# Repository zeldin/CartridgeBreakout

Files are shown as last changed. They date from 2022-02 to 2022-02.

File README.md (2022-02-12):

Cartridge Breakout
==================

This is a PCB to break out the signals of a 44-contact 2.54 mm card edge
connector, as used in cartridges for the C64, to pin headers.  It was
designed for use with the Orange Cartridge, but can be used with any C64
cartridge, or even other compatible card edge devices.

The board can be used for testing, debugging and prototyping cartridges
and FPGA cartridge gateware and software.

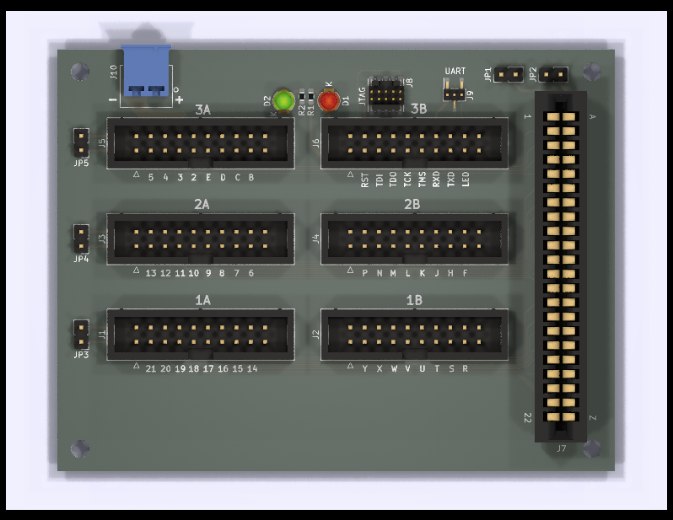
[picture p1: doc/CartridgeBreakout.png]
Render of the board


Features
--------

- 40 of the 44 contacts are routed to individual pins compatible
  with IDC or Dupont wiring.

- The 4 corner contacts are instead connected to a ground plane
  which is available on 40 pins, one for each signal pin.

- There is a 5V power plane which can be used to inject power into
  contacts 2 and 3, or just one of them if so desired.

- There is a 5-signal JTAG/SWD breakout from a 2x5 1.27 mm pin header,
  as a wired side channel to the cartridge.

- There is also a 2-signal UART breakout from a 1x3 1.27 mm pin header,
  likewise a wired side channel.

- There are two LEDs which can be controlled with a single pin, to support
  semi-automated testing setups.

Documentation
-------------

**[Building instructions](doc/Building.md)**  
**[User manual](doc/UserManual.md)**

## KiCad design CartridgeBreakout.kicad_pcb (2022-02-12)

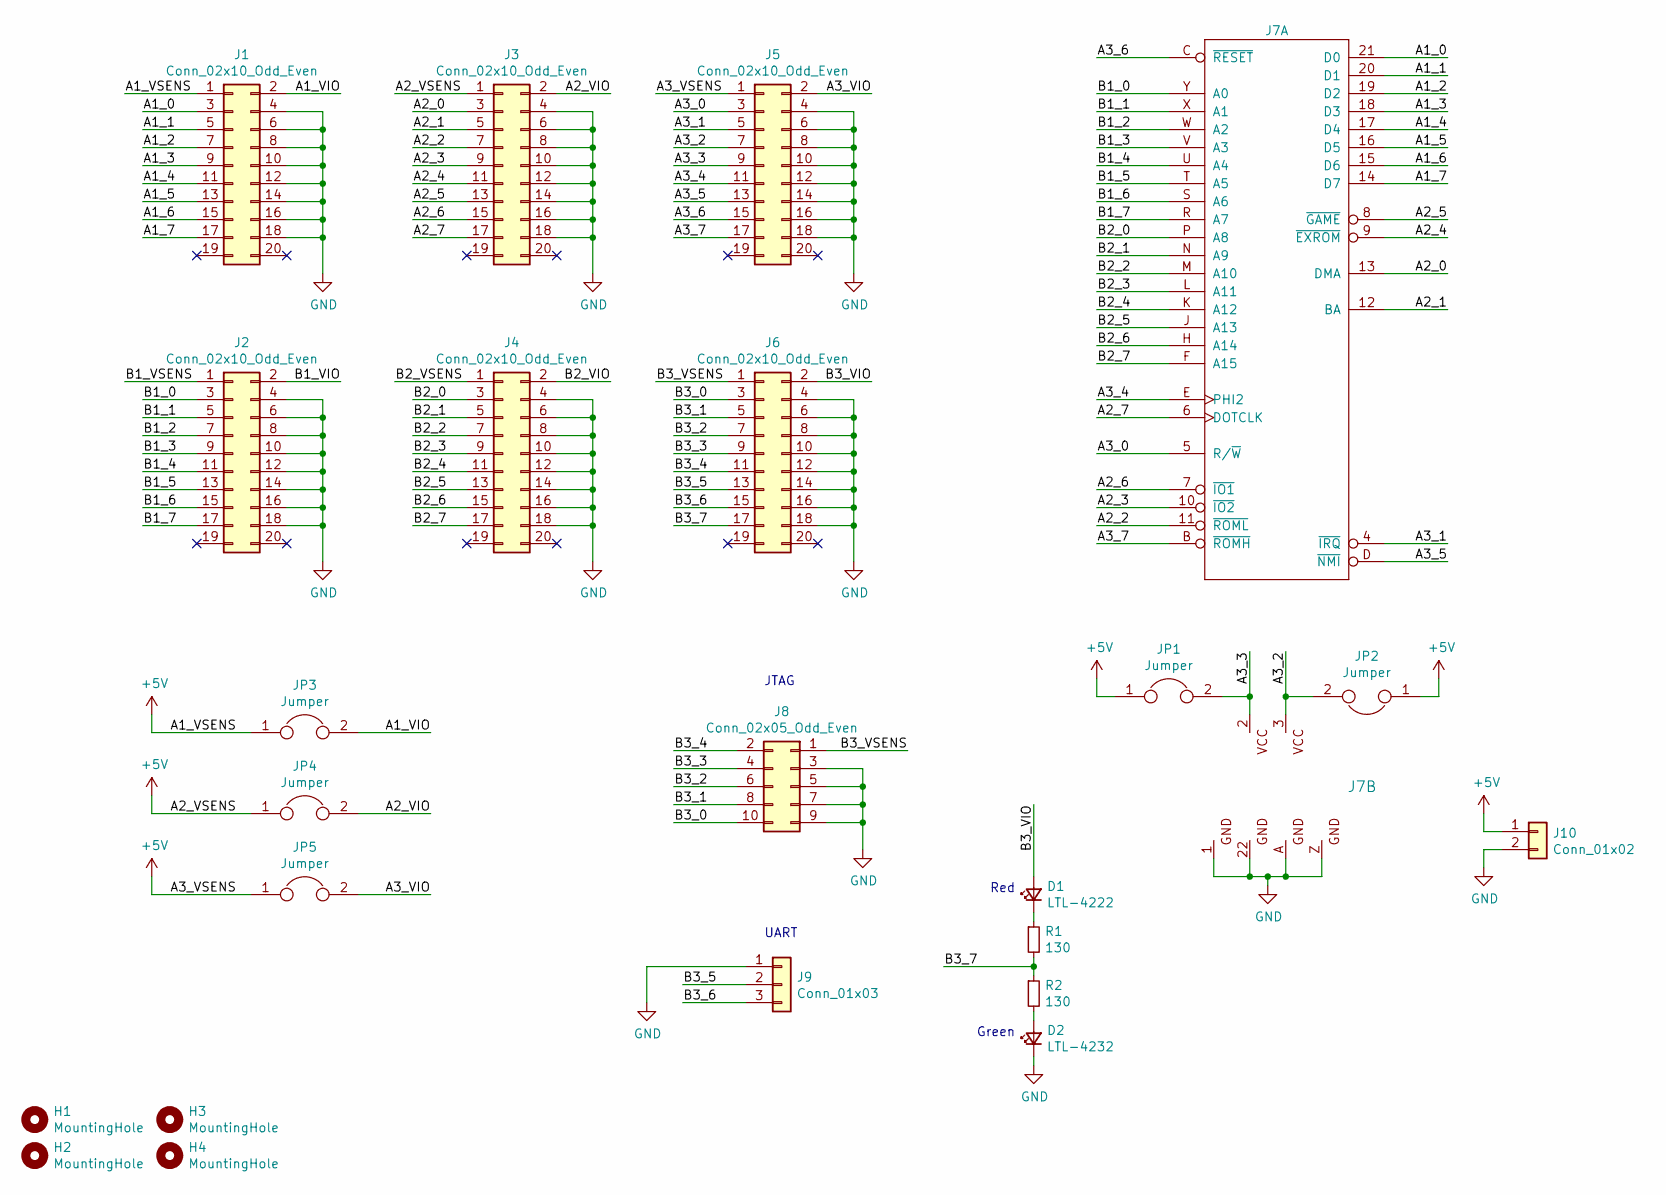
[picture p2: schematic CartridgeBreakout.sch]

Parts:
D1: LTL-4222; LED_D3.0mm; Mouser SKU 859-LTL-4222
D2: LTL-4232; LED_D3.0mm; Mouser SKU 859-LTL-4232
H1, H2, H3, H4: MountingHole; MountingHole_3.2mm_M3
J1, J2, J3, J4, J5, J6: Conn_02x10_Odd_Even; IDC-Header_2x10_P2.54mm_Vertical; Mouser SKU 538-87834-2019
J7: EXPANSION_PORT_C64_EDGE; TE_5530843-4; Mouser SKU 571-5530843-4
J8: Conn_02x05_Odd_Even; FTSH-105-XX-X-DV; Mouser SKU 200-FTSH10501FDVKTR
J9: Conn_01x03; PinHeader_1x03_P1.27mm_Vertical_SMD_Pin1Right; Mouser SKU 855-M50-3630342
J10: Conn_01x02; 284512-2; Mouser SKU 571-284512-2
JP1, JP2, JP3, JP4, JP5: Jumper; PinHeader_1x02_P2.54mm_Vertical; Mouser SKU 538-22-28-4023
R1, R2: 130; R_0603_1608Metric_Pad0.98x0.95mm_HandSolder; Mouser SKU 603-AC0603JR-07130RL

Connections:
+5V: J1.1, J3.1, J5.1, J10.1, JP1.1, JP2.1, JP3.1, JP4.1, JP5.1
/A1_0: J1.3, J7.21 (D0)
/A1_1: J1.5, J7.20 (D1)
/A1_2: J1.7, J7.19 (D2)
/A1_3: J1.9, J7.18 (D3)
/A1_4: J1.11, J7.17 (D4)
/A1_5: J1.13, J7.16 (D5)
/A1_6: J1.15, J7.15 (D6)
/A1_7: J1.17, J7.14 (D7)
/A1_VIO: J1.2, JP3.2
/A2_0: J3.3, J7.13 (DMA)
/A2_1: J3.5, J7.12 (BA)
/A2_2: J3.7, J7.11 (~ROML)
/A2_3: J3.9, J7.10 (~IO2)
/A2_4: J3.11, J7.9 (~EXROM)
/A2_5: J3.13, J7.8 (~GAME)
/A2_6: J3.15, J7.7 (~IO1)
/A2_7: J3.17, J7.6 (DOTCLK)
/A2_VIO: J3.2, JP4.2
/A3_0: J5.3, J7.5 (R/~W)
/A3_1: J5.5, J7.4 (~IRQ)
/A3_2: J5.7, J7.3 (VCC@1), JP2.2
/A3_3: J5.9, J7.2 (VCC), JP1.2
/A3_4: J5.11, J7.E (PHI2)
/A3_5: J5.13, J7.D (~NMI)
/A3_6: J5.15, J7.C (~RESET)
/A3_7: J5.17, J7.B (~ROMH)
/A3_VIO: J5.2, JP5.2
/B1_0: J2.3, J7.Y (A0)
/B1_1: J2.5, J7.X (A1)
/B1_2: J2.7, J7.W (A2)
/B1_3: J2.9, J7.V (A3)
/B1_4: J2.11, J7.U (A4)
/B1_5: J2.13, J7.T (A5)
/B1_6: J2.15, J7.S (A6)
/B1_7: J2.17, J7.R (A7)
/B1_VIO: J2.2
/B1_VSENS: J2.1
/B2_0: J4.3, J7.P (A8)
/B2_1: J4.5, J7.N (A9)
/B2_2: J4.7, J7.M (A10)
/B2_3: J4.9, J7.L (A11)
/B2_4: J4.11, J7.K (A12)
/B2_5: J4.13, J7.J (A13)
/B2_6: J4.15, J7.H (A14)
/B2_7: J4.17, J7.F (A15)
/B2_VIO: J4.2
/B2_VSENS: J4.1
/B3_0: J6.3, J8.10
/B3_1: J6.5, J8.8
/B3_2: J6.7, J8.6
/B3_3: J6.9, J8.4
/B3_4: J6.11, J8.2
/B3_5: J6.13, J9.2
/B3_6: J6.15, J9.3
/B3_7: J6.17, R1.2, R2.1
/B3_VIO: D1.2 (A), J6.2
/B3_VSENS: J6.1, J8.1
GND: D2.1 (K), J1.4, J1.6, J1.8, J1.10, J1.12, J1.14, J1.16, J1.18, J2.4, J2.6, J2.8, J2.10, J2.12, J2.14, J2.16, J2.18, J3.4, J3.6, J3.8, J3.10, J3.12, J3.14, J3.16, J3.18, J4.4, J4.6, J4.8, J4.10, J4.12, J4.14, J4.16, J4.18, J5.4, J5.6, J5.8, J5.10, J5.12, J5.14, J5.16, J5.18, J6.4, J6.6, J6.8, J6.10, J6.12, J6.14, J6.16, J6.18, J7.1 (GND), J7.22 (GND@1), J7.A (GND@2), J7.Z (GND@3), J8.3, J8.5, J8.7, J8.9, J9.1, J10.2
unnamed: D1.1 (K), R1.1
unnamed: D2.2 (A), R2.2

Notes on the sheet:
JTAG
UART
Red
Green

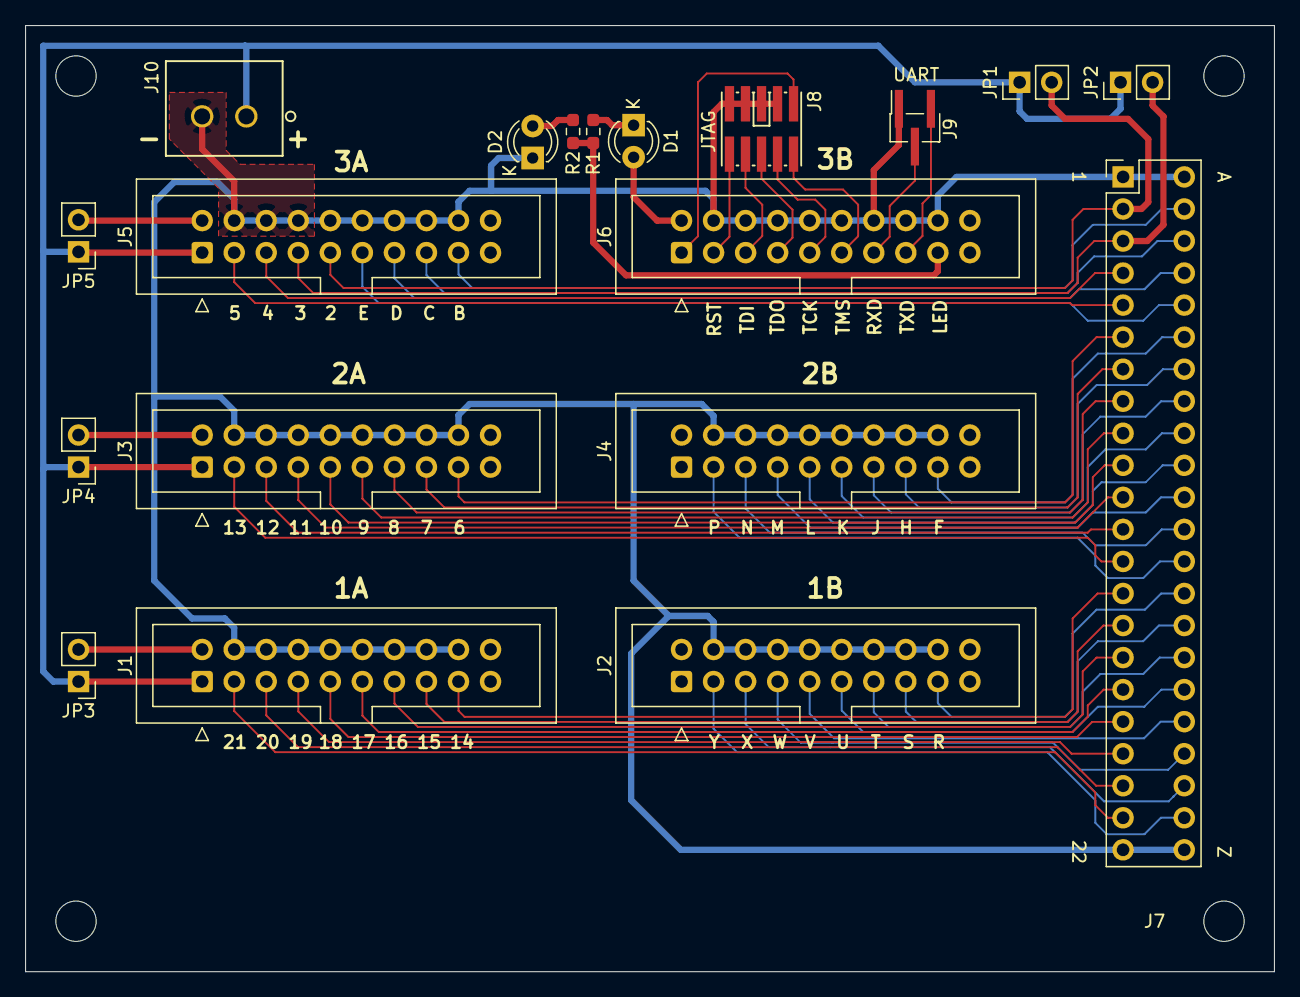
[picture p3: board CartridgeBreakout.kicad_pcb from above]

Board: 2 copper layers, 99.0 x 75.0 mm, 23 parts (0 on the bottom side), 57 nets.

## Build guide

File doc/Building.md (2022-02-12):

Building instructions
=====================

Preparation
-----------

The cartridge breakout takes about one hour to build.  Before
starting, check that you have everything of the following.

### Equipment required

* Soldering iron
* Tweezers, for manipulating the surface mount components
* Wire cutters, for adjusting the length of the LED pins
* Some solder

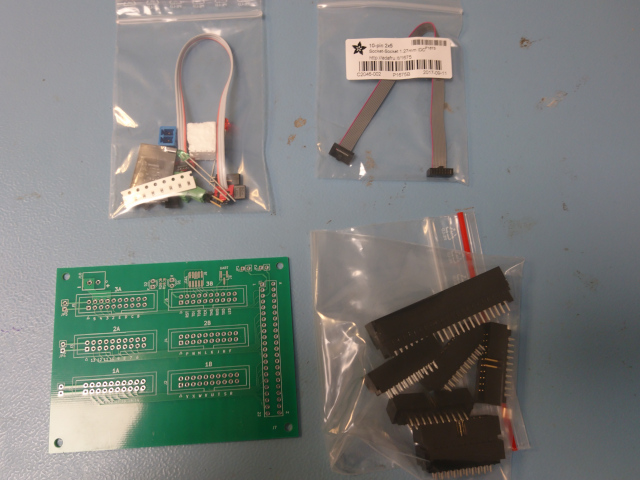
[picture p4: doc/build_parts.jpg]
Parts needed


### PCB

* The printed circuit board to populate

### Large components

* 2x10 pin headers (6)
* 44 pin card edge connector

### Small components

* 130 ohm resistors, size 0603 (a bunch, in case you drop some
                                and never find them again :)
* 2x5 1.27 mm surface mount pin header for JTAG
* 1x3 1.27 mm surface mount pin header for UART
* Right angle 3.5 mm header for power
* 1x2 pin headers for jumpers (5)
* Red 3 mm LED
* Green 3 mm LED

### Accessories

* Pluggable screw terminals for power
* Jumpers
* 3-pin UART cable
* 10-pin JTAG cable

Surface mount components
------------------------

The first step is to mount the surface mount components.  These
components are all optional and not related to the core functionality
of cartridge pin breakout and power supply, but if you are ever going
to mount these components, now is the time to do it, when there is no
solder on the bottom of the board making it uneven, or any large
components (the 20 pin headers in particular) on the top side getting
in the way.  So even if you have no immediate plans for these
functions, I recommend at least giving it a try.  Each surface mount
component relates to one separate function (red LED, green LED, JTAG
side channel, UART side channel), so even if mounting one component
fails, it won't affect any other functionality on the board.

## Resistors

Mount two 130 ohm resistors as shown in the picture.  Use tweezers to
hold the resistors down when soldering, so that they do not get stuck
on the soldering iron.

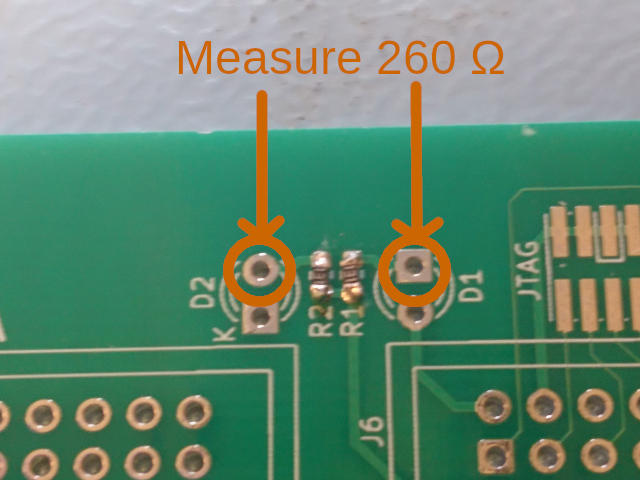
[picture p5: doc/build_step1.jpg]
Resistors mounted on PCB


When the resistors are correctly mounted, you should be able to
measure about 260 ohms of resistance between the indicated pads.
If you measure infinity (or more than 1k at least) ohms, there is
a bad solder joint.  If you measure 0 ohms, there is a short circuit.
If you measure 130 ohms, then either there is a short circuit or you
mounted the resistors rotated 90 degrees.  :-)

## Side channel pin headers

Next, mount the two surface mount pin headers for the side channels (JTAG
and UART).  Mind the orientation of the key slot on the 2x5 pin header.
Hold down each header with tweezers and solder one pin first, and then
after inspecting that all pins are correctly aligned solder the rest of
the pins, starting on the opposite side from the pin you soldered first.
Don't use too much solder.  You can use flux if you have it, but it's not
necessary.

Use an ohm meter to check the connections.  With the exception of
the ground pins (the leftmost pin on the UART connector, and the
4 top left pins on the UART connector), each pin should be connected to
exactly one pin on the lower row of 3B, and to none on the top row.
The ground pins should be connected to the middle 8 pins of the top
row of 3B.

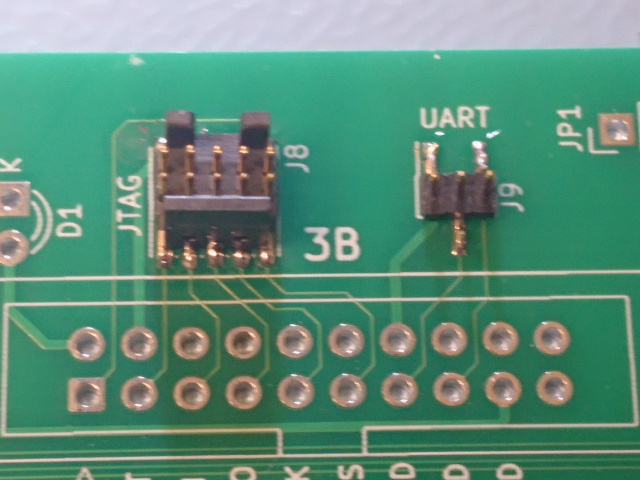
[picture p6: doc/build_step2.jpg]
Surface mount headers mounted on PCB


Through hole connectors
-----------------------

After the surface mount components are in place, it's time to mount
all those through hole pin headers.  This is done starting with
the lowest header and ending with the highest, so that the workbench
can be used to keep the headers pushed against the PCB when soldering.

## Power header

These headers come with housings in both blue and green.  There is
no difference except for the actual color.  Mount it as shown in
the picture.

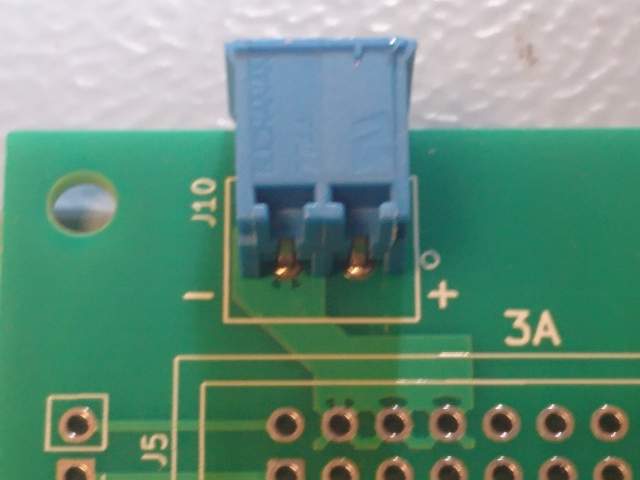
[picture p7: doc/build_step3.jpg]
Right angle power header mounted on PCB


## Jumper headers

These can be a bit tricky to get completely vertical.  Solder one pin
first and check on the top side if there is a significant tilt before
soldering the other one.

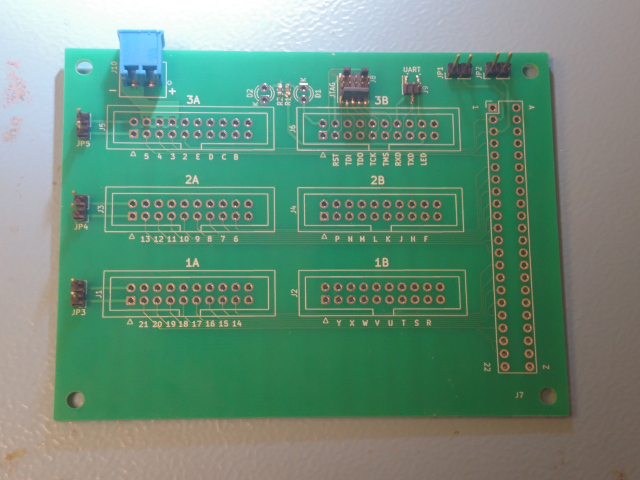
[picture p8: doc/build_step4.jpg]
Jumper headers mounted on PCB


## 2x10 pin headers

When soldering the 2x10 pin headers, be careful with the orientation
of the key slot in the shroud.  It should be pointing towards the bottom
of the board, as indicated by the silkscreen markings.

Solder two corner pins first and then double check the orientation on
the top side before soldering the rest.

If you start by inserting header 1A and 3B at the same time, flipping
the board over and soldering the corner pins, the PCB will have a stable
base to rest on, making soldering easier.

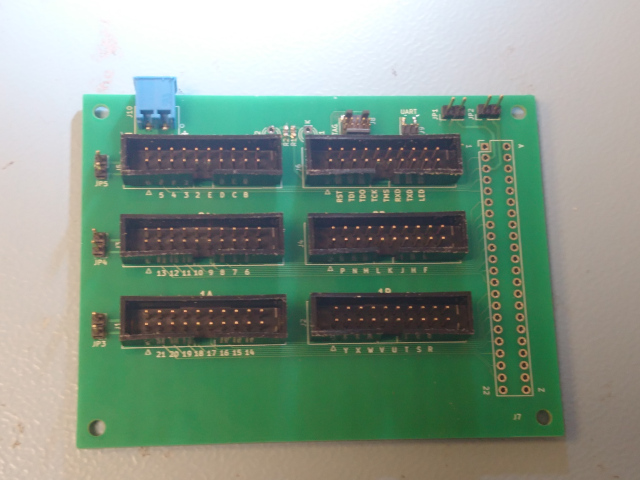
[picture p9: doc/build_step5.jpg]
2x10 pin headers mounted on PCB


## Card edge connector

This connector has small markings indicating pin "1" and "43",
but is otherwise completely symmetrical, so just mount it in
either of the two possible orientations.

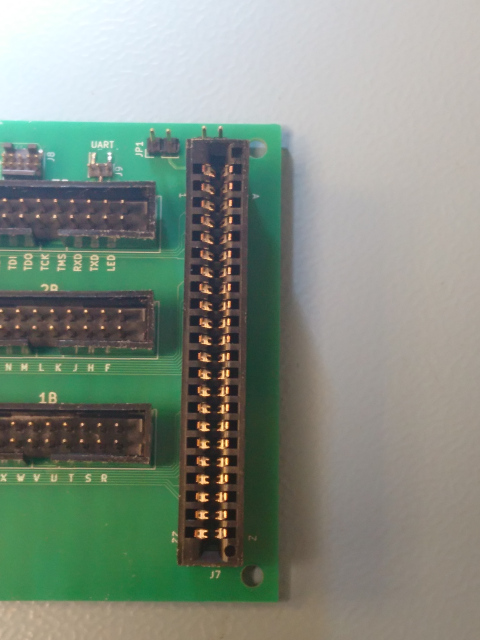
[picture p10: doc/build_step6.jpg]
Card edge connector mounted on PCB


LEDs
----

Now the only thing left to mount is the LEDs.  If you did not mount
the resistors in the first step, don't mount the LEDs now.  They will
not work without the resistors, and if you should decide to mount the
resistors later it's better to mount the LEDs _after_ that.

When mounting the LEDs, make sure to observe the polarity, which
should be different on the two.  The shorter pin is the cathode and
goes into the hole marked "K".  Another way to check is that the side
of the dome which has a flat portion at the bottom should be facing
the side with the hole that has a square pad.

Don't trim the length of the pins until after you solder.  Just bend them
to keep the LED in place while soldering, and cut them afterwards.

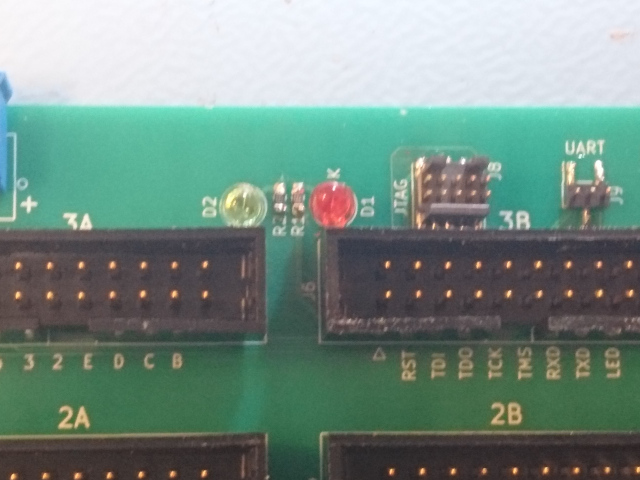
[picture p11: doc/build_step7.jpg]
LEDs mounted on PCB


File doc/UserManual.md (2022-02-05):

User Manual
===========

Cartridge connection
--------------------

The cartridge is inserted in connector J7, with the top side facing
inwards.  The silk screen indicates the positions of contact 1 and 22,
on the top side, and A and Z, on the bottom side.  When inserting a
board without a case guiding the position, mind the proper alignment
of the card edge contacts against those in the connector.

Cartridge signal break-outs
---------------------------

The 40 non-ground cartridge signals are available on the connectors
"1A", "1B", "2A", "2B", and "3A" (designation J1 through J5), 8 signals
in each connector.  Each connector also has 8 ground connections.

The pinout of each 20-pin connector is as follows:

| 2 | 4 | 6 | 8 | 10 | 12 | 14 | 16 | 18 | 20 | | VOUT | GND | GND | GND | GND | GND | GND | GND | GND | NC | | VIN | IO0 | IO1 | IO2 | IO3 | IO4 | IO5 | IO6 | IO7 | NC | | 1 | 3 | 5 | 7 | 9 | 11 | 13 | 15 | 17 | 19 |

For the mapping of the IO signals, please refer to the markings on the
silk screen, or to the tables at the end of this document.

All the IO pins are connected directly to the corresponding contact on
the cartridge, meaning that the signal levels are 5V.  For VOUT and VIN,
see next section.

Note that in the case of the Orange Cartridge, power must be applied
through the card edge connector for the IO signals to be active.  When
the cartridge is powered only through the USB port, the level shifters
are disabled preventing FPGA signals from reaching the card edge connector.

+5V power plane
---------------

C64 cartidges receive +5V power through contacts 2 and 3 on the card edge
connector.  While it is possible to feed power into these contacts using
the corresponding break-out pins on connector 3A, they can also be fed
from a separate power plane, by installing jumper JP1 and/or JP2.

| Jumper | Function when installed |
| --- | --- |
| JP1 | Contact 2 receives power from the power plane |
| JP2 | Contact 3 receives power from the power plane |

There is no back-current protection provided, so do not connect a
power supply to the break-outs for contact 2 or 3 when the
corresponding contact is powered from the power plane.  The break-out
pins can still be used to monitor the voltage, if desired.

Feeding the power plane from a +5V power supply can be done through the
pluggable screw terminal J10.  Observe the polarity as indicated on the
silk screen.

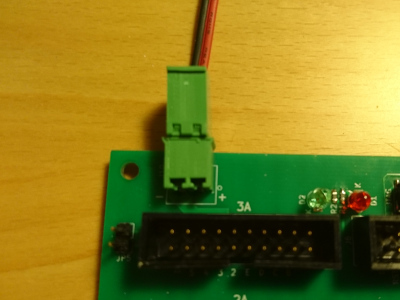
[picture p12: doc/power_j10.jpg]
Power plane powered through screw terminals


The 20-pin connectors 1A, 2A and 3A also provide an interface to the
power plane.  The VIN pins are always connected to the power plane,
and are intended for monitoring the voltage level.  The VOUT pins are
intended for feeding the power plane, and can be connected or
disconnected from the power plane using jumpers located next to the
connector.  Do not install these jumpers when feeding the power plane
through J10.

| Jumper | Function when installed |
| --- | --- |
| JP3 | The power plane receives power from VOUT on 1A |
| JP4 | The power plane receives power from VOUT on 2A |
| JP5 | The power plane receives power from VOUT on 3A |

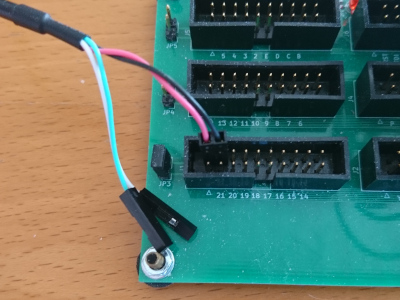
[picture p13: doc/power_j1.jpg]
Power plane powered through connector 1A using Adafruit 954 cable


Side channel connector
----------------------

Connector "3B" (designation J6) is not connected to the card edge
connector.  Instead it provides break-outs for connector J8 and J9,
which can be connected to the cartridge (or other eqiupiment) using
cables.  These signals will typically use different voltage levels
from the signals on the card edge connector.  In the case of the
Orange Cartridge, all signals on this connector use 3.3V levels,
and are operational also when the cartridge is only powered through
the USB connector.

J8 is a 2x5 1.27 mm keyed pin header intended for connection to an
"SWD" style JTAG connector.  This carries the 4 mandatory JTAG signals
as well as a reset signal (typically SRST), all of which are broken
out on connector 3B.  Please refer to the silk screen markings or the
tables at the end of this document for the mapping.  The reference
voltage present in the SWD connector is routed to the VIN pin of 3B.

J9 is a 1x3 1.27 mm pin header intended for a debug UART.  Pin 1 is
connected to GND, and the other two are routed to 3B as "RXD" and "TXD".
Be careful with the orientation and alignment when inserting a cable into
J9, as there is no keying.

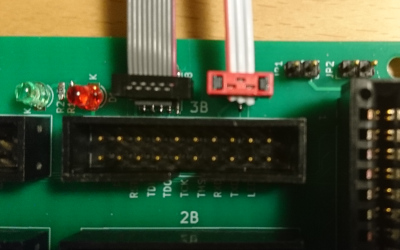
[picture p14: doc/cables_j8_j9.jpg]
Correct cable orientation for J8 and J9


LEDS
----

There are two LEDs on the board intended for use with semi-automated
testing.  They are controlled by the LED pin (IO7) of connector 3B,
according to the following scheme:

| LED pin voltage relative to GND | Function |
| --- | --- |
| Floating | Both LEDs off |
| 0V | Red LED on |
| +3.3V | Green LED on |

There is no support for turning on both LEDs at the same time.  Note
that for the red LED to be operational, VOUT on 3B must be driven to
+3.3V relative to the common GND.

IO mapping tables
-----------------

The following are the pin mapping tables for the individual 20-pin
connectors.

### 1A

| Pin | Signal |
| ----- | --- |
| IO0 | 21 (D0) |
| IO1 | 20 (D1) |
| IO2 | 19 (D2) |
| IO3 | 18 (D3) |
| IO4 | 17 (D4) |
| IO5 | 16 (D5) |
| IO6 | 15 (D6) |
| IO7 | 14 (D7) |
| VIN | Power plane sense |
| VOUT  | Power plane feed through JP3 |

### 1B

| Pin | Signal |
| ----- | --- |
| IO0 | Y (A0) |
| IO1 | X (A1) |
| IO2 | W (A2) |
| IO3 | V (A3) |
| IO4 | U (A4) |
| IO5 | T (A5) |
| IO6 | S (A6) |
| IO7 | R (A7) |
| VIN | No connection |
| VOUT  | No connection |

### 2A

| Pin | Signal |
| ----- | --- |
| IO0 | 13 (DMA) |
| IO1 | 12 (BA) |
| IO2 | 11 (_ROML) |
| IO3 | 10 (_IO2) |
| IO4 | 9 (_EXROM) |
| IO5 | 8 (_GAME) |
| IO6 | 7 (_IO1) |
| IO7 | 6 (DOT Clk) |
| VIN | Power plane sense |
| VOUT  | Power plane feed through JP4 |

### 2B

| Pin | Signal |
| ----- | --- |
| IO0 | P (A8) |
| IO1 | N (A9) |
| IO2 | M (A10) |
| IO3 | L (A11) |
| IO4 | K (A12) |
| IO5 | J (A13) |
| IO6 | H (A14) |
| IO7 | F (A15) |
| VIN | No connection |
| VOUT  | No connection |

### 3A

| Pin | Signal |
| ----- | --- |
| IO0 | 5 (R/_W) |
| IO1 | 4 (_IRQ) |
| IO2 | 3 (+5V DC) |
| IO3 | 2 (+5V DC) |
| IO4 | E (PHI2) |
| IO5 | D (_NMI) |
| IO6 | C (_RESET) |
| IO7 | B (_ROMH) |
| VIN | Power plane sense |
| VOUT  | Power plane feed through JP5 |

### 3B

| Pin | Signal |
| ----- | --- |
| IO0 | J8 (JTAG) nRESET (pin 10) |
| IO1 | J8 (JTAG) TDI (pin 8) |
| IO2 | J8 (JTAG) TDO/SWO (pin 6) |
| IO3 | J8 (JTAG) TCK/SWDCLK (pin 4) |
| IO4 | J8 (JTAG) TMS/SWDIO (pin 2)  |
| IO5 | J9 (UART) RXD (pin 2) |
| IO6 | J9 (UART) TXD (pin 3) |
| IO7 | Red/green LED control |
| VIN | J8 (JTAG) VREF (pin 1) |
| VOUT  | Red LED +3.3V power feed |
